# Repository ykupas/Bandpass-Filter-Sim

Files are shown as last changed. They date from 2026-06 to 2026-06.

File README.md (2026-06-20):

# Bandpass-Filter-Sim

Bandpass filter project and simulation using KiCAD (v9.0.9), FreeCAD (v1.1.1) and EMerge Software (v2.7.3) to get S parameters from a PCb design.

## 5th Bandpass Filter

The filter was designed from Marki Microwave, in this [link](https://markimicrowave.com/technical-resources/tools/lc-filter-design-tool/). It is a 5th order Chebyshev bandpass with lower cutoff frequency of 90MHz, and upper cutoff frequency of 110MHz. Passband ripple of 0.1dB, capacitors and inductors tolerance of 5% and commercial values.

The design can be viewed in SCH from KiCAD, with the results from Marki Microwave and KiCAD simulation.

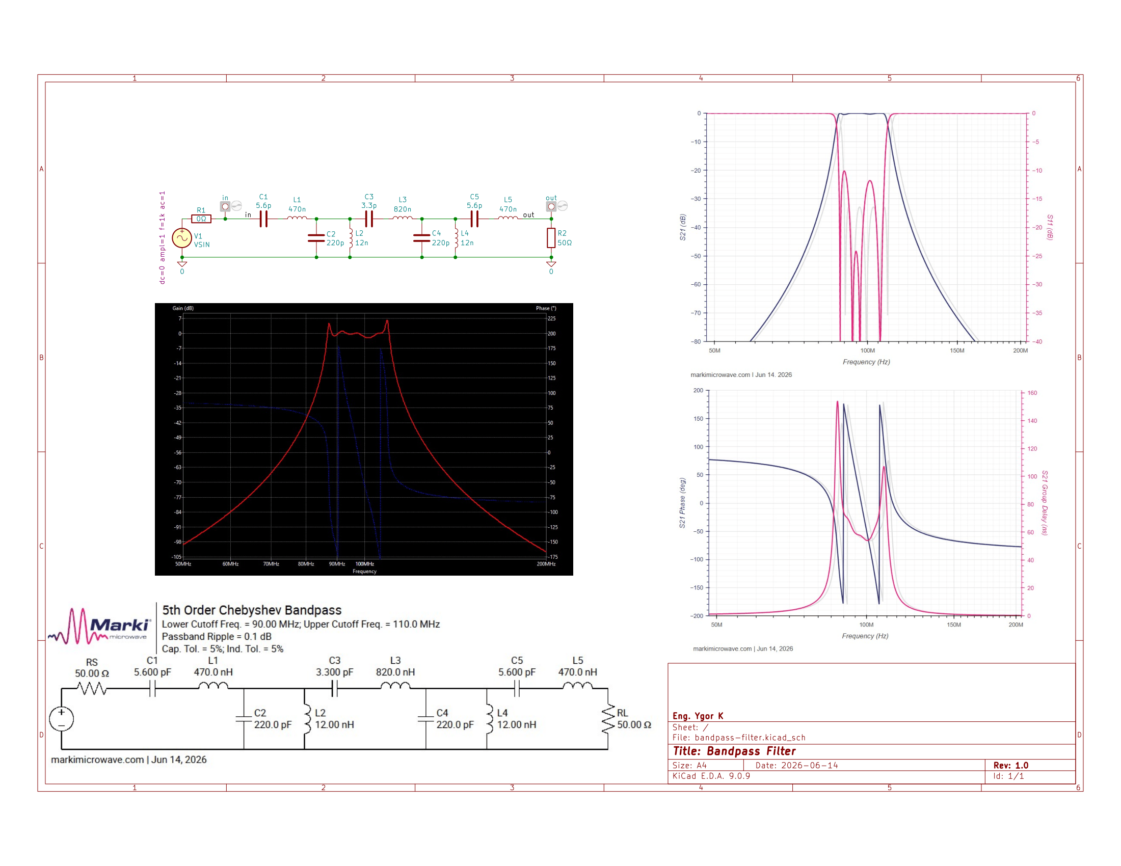
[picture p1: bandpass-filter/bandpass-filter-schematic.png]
SCH


## Simulation in EMerge

With the KiCAD design done, the next step was to model in FreeCAD and simulate in EMerge with the help of the macro FreeCAD-OpenEMS-Export. After modeling, meshing it and simulating, the results are shown below.

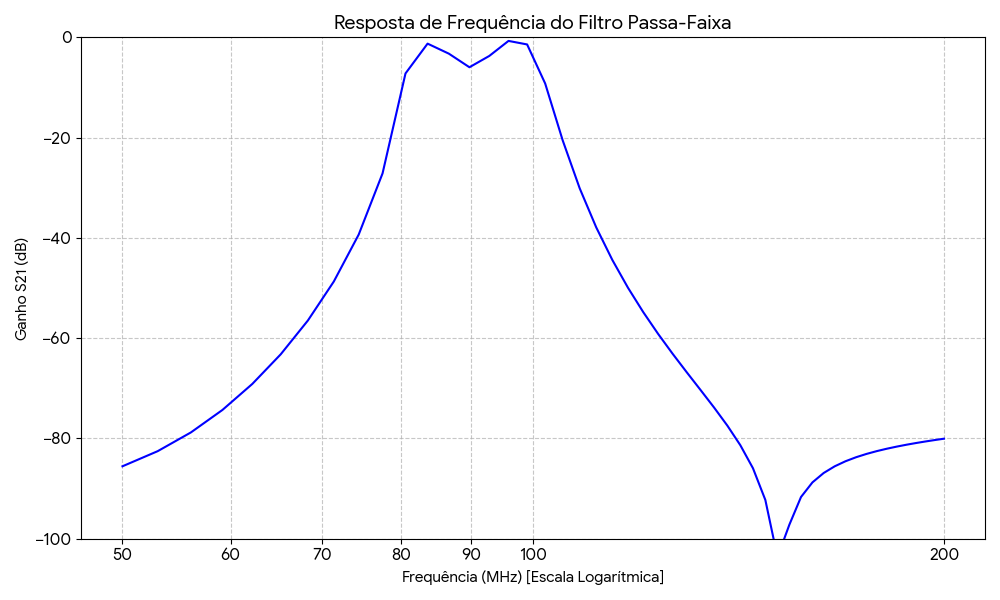
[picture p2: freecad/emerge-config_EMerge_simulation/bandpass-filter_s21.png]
SIM


Some points are not the same because of RAM limitations in my machine, I was using only 50 points to calculate it. But it shown a good result for a simple model.

## Future works

This simulation demonstrate an example of modeling lumped components in FreeCAD for EMerge software this. Merging this feature with PCB Antenna desing, full RF systems can be simulate using open source software, as matching networks and some crazy antenna designs! Thanks for spending time here with me.

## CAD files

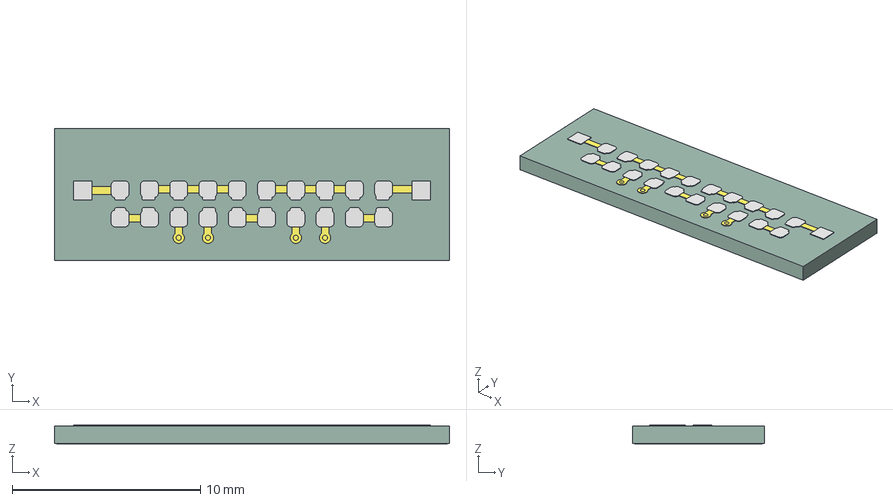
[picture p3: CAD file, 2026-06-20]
freecad/bandpass-filter.step
21.0 x 7.00 x 1.00 mm
bandpass-filter_copper
bandpass-filter_pad
bandpass-filter_via
bandpass-filter_PCB

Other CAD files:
freecad/bandpass-filter.FCStd

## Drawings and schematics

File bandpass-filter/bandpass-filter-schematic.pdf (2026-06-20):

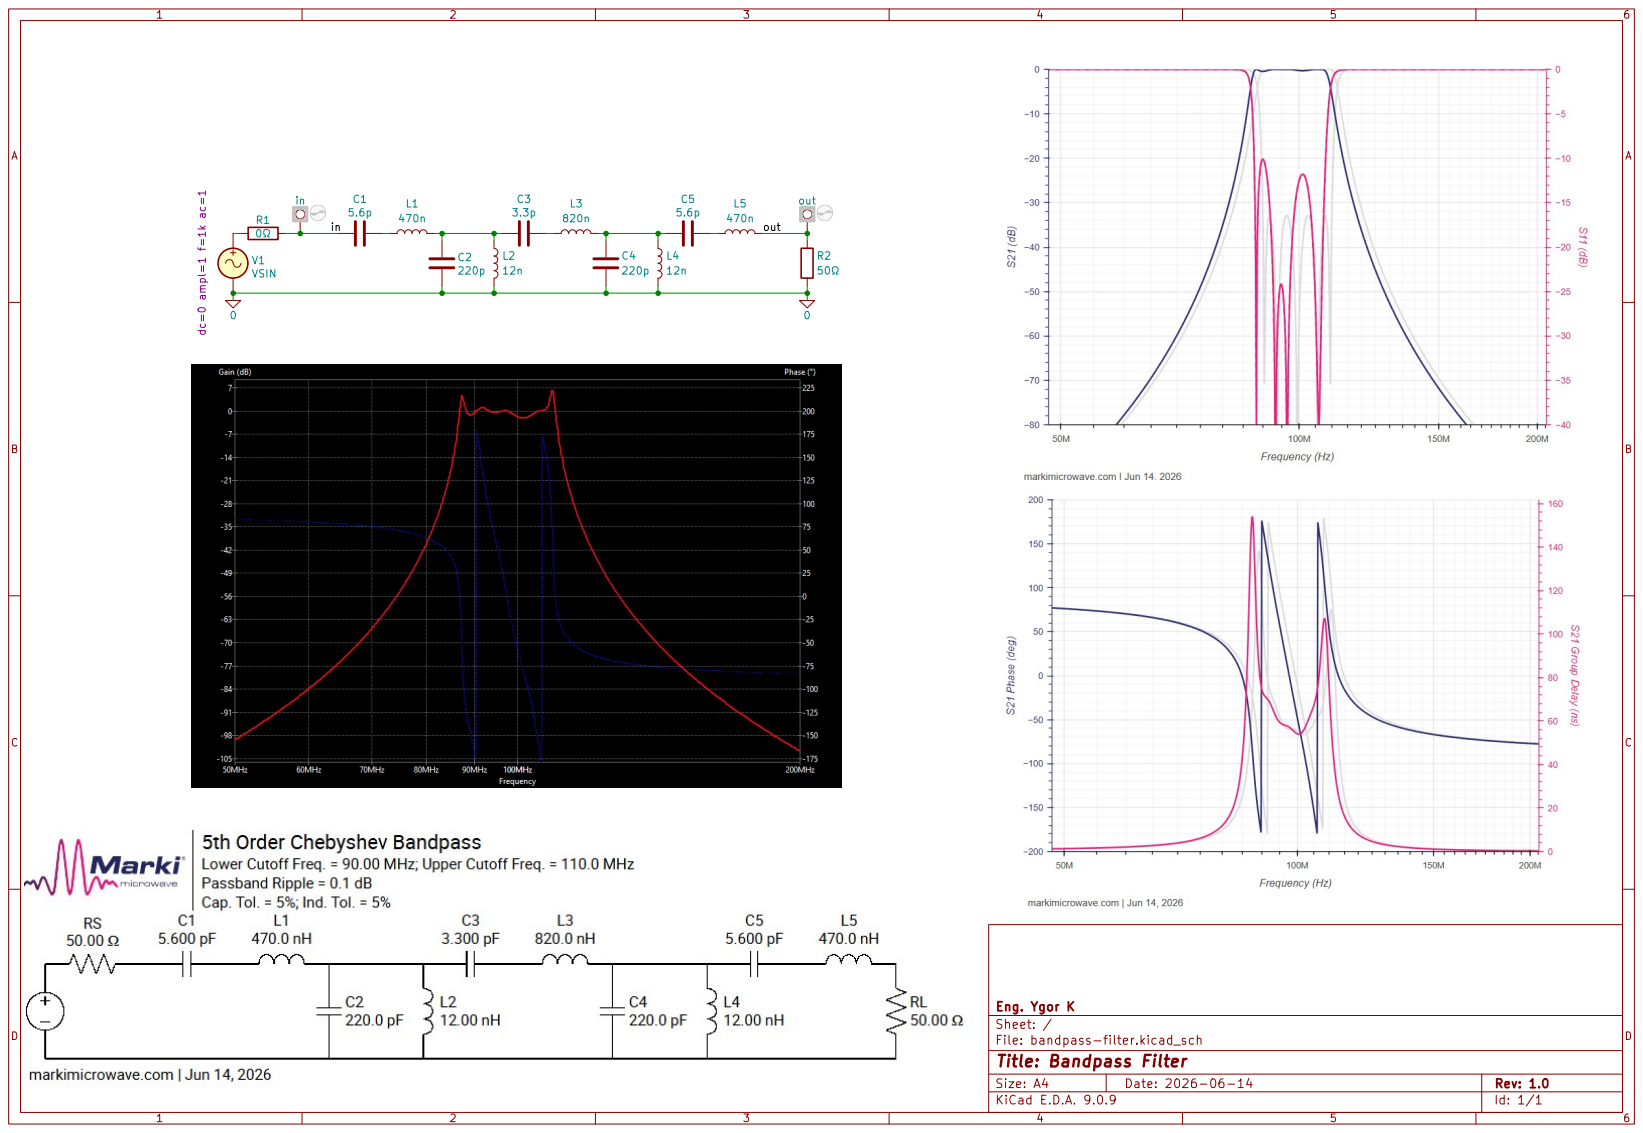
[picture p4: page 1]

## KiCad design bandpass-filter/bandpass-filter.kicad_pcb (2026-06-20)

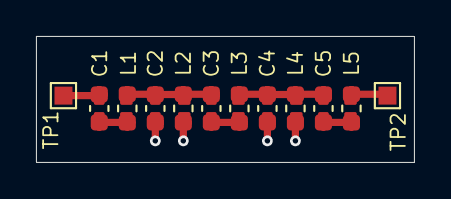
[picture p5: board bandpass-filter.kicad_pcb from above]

Board: 2 copper layers, 21.0 x 7.0 mm, 12 parts (0 on the bottom side), 8 nets.

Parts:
C1, C5: 5.6p; C_0603_1608Metric_femSolver
C2, C4: 220p; C_0603_1608Metric_femSolver
C3: 3.3p; C_0603_1608Metric_femSolver
L1, L5: 470n; L_0603_1608Metric_femSolver
L2, L4: 12n; L_0603_1608Metric_femSolver
L3: 820n; L_0603_1608Metric_femSolver
TP1: in; TestPoint_Pad_1.0x1.0mm
TP2: out; TestPoint_Pad_1.0x1.0mm

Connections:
0: C2.2, C4.2, L2.2, L4.2
/in: C1.1, TP1.1
/out: L5.2, TP2.1
unnamed: C1.2, L1.1
unnamed: C2.1, C3.1, L1.2, L2.1
unnamed: C3.2, L3.1
unnamed: C4.1, C5.1, L3.2, L4.1
unnamed: C5.2, L5.1

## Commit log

2026-06-14 Creating SCH and circuit images.
    [bandpass-filter.kicad_pcb, bandpass-filter.kicad_sch]
2026-06-14 Schematic and Spice simulation complete, missing layout and EMerge simulation.
    [bandpass-filter.kicad_pcb, bandpass-filter.kicad_sch]
2026-06-14 Layout done, ready to export to FreeCAD.
    [bandpass-filter.kicad_pcb, bandpass-filter.kicad_sch]
2026-06-15 Adding FreeCAD file.
    [bandpass-filter.FCStd]
2026-06-15 Changing PCB layout.
    [bandpass-filter.kicad_pcb, bandpass-filter.kicad_sch]
2026-06-15 Adding FreeCAD temporary file to gitignore.
    [bandpass-filter.FCStd]
2026-06-15 Adding model to FreeCAD and creating config file for simulation.
    [bandpass-filter.FCStd, bandpass-filter.step]
2026-06-19 Changing PCB model to top, bot, via, PCB, lumped, ports and air.
    [bandpass-filter.FCStd]
2026-06-19 It does not have enough memory for this mesh!
    [bandpass-filter.FCStd]
2026-06-20 CHanging top layer model for compacting mesh.
    [bandpass-filter.FCStd, bandpass-filter.kicad_pcb, bandpass-filter.step]
